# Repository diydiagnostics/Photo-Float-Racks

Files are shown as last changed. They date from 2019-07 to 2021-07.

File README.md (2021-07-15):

## Photo-Float-Racks

## Welcome to the  [DIY Diagnostics](https://diystream.cns.utexas.edu/ "DIY Diagnostics")  [Freshman Research Initiative](https://cns.utexas.edu/fri "Freshman Research Initiative") repository for improved water bath floats.

This repository was created by Niam Kuttanna, Andrew Kan, and Haroon Dossani under the supervision of Dr. Timothy Riedel. It represents an archive of various designs for 3D printed float racks.

# Table of Contents:
1. [Purpose](#Purpose)
2. [Case Study](#Case-Study)
3. [Designs](#Designs)
4. [3D Printing Specifications](#3D-Printing-Specifications)
5. [3D Printing Guide](#3D-Printing-Guide)

## Purpose
Water bath floats are often not optimized for taking photographs of the reaction tubes during incubation. Often the process of inspecting assays comprises three steps: removing the water bath lid; detaching assay tubes from floating sponges; and holding up tube strips for visual inspection or photography. This yields inconsistent images, wastes valuable time, and introduces a host of factors that can affect the certainty of future results (i.e. temperature variation from leaving the water bath open while removing and replacing reaction tubes).

The combination 0.2 ml tube rack/floats described below simplify the process of running and imaging reactions. They are easily printed with a consumer grade 3D printer and the design files are downloadable from this repository. The racks provides for straightforward solution pipetting and ensures a secure hold on the standard 8-tube strip. The tube rack floats so the reactions and rack can be dropped in a water bath directly without the need to transfer the tubes to a float.

These racks are designed for easy assay inspection. The rack designs include a solid color background that enables the entire rack (with tubes) to be lifted out of the water bath and photographed directly. There is no need to transfer the tubes to another holder. 

In addition we have designed a "photo booth" hood that the rack can sit directly on to provide consistent background lighting and focal distance from a smartphone. 

## Case-Study
The [DIY Diagnostics](https://diystream.cns.utexas.edu/ "DIY Diagnostics") lab heavily utilizes the NEB 
[Colorimetric LAMP 2X Master Mix](https://www.neb.com/products/m1800-warmstart-colorimetric-lamp-2x-master-mix-dna-rna#Product%20Information "Colorimetric LAMP 2X Master Mix") to develop sequence specific diagnostic tests. During development we take many photographs over timepoints and the racks described in this repository have enabled more accurate documentation of the diagnostic performance.

ResearchingwithFloatRack

## Designs
alldesigns

First Row (left to right):
- 8C Prototype 1*
- [8C Original.stl]
- [8C Original.stl]**
- [8C Light.stl]
- [3C - Original.stl]
- [IS - Horizontal.stl]

Second Row (left to right):
- LAMP Box Prototype 1
- 16C Sled*
- [8C Side Clip Handle.stl]
- [8C Side Clip Handle + Backdrop.stl]
- [16C Peg Handle.stl]**
- IS Vertical Prototype 1*

Third Row (left to right):
- [16C Dual Handle.stl]
- [16C Peg Handle.stl]**
- [16C Peg Handle.stl]
- [16C Peg Handle.stl]
- [16C Clip Handle.stl]
- [IS - Vertical 2.0.stl] - pre-handle clip compatibility

//* Obsolete design
//** PLA, non-recommended material

### [16 Capacity Designs](https://github.com/diydiagnostics/LAMP-Float-Racks/tree/master/16%20Capacity%20Designs)

### [8 Capacity Designs](https://github.com/diydiagnostics/LAMP-Float-Racks/tree/master/8%20Capacity%20Designs)

### [9 Capacity Designs](https://github.com/diydiagnostics/LAMP-Float-Racks/tree/master/9%20Capacity%20Designs)

### [Imaging Systems](https://github.com/diydiagnostics/LAMP-Float-Racks/tree/master/Imaging%20System%20Designs)

### [Miscellaneous Designs](https://github.com/diydiagnostics/LAMP-Float-Racks/tree/master/Miscellaneous%20Designs)

## 3D Printing Specifications

- Recommended: ABS filament only for float rack use due to its temperature resistance at 60-70℃

- 🔥 = Developer's Choice

Design Name | Filament  | 3D Printer  | Extrusion Speed | Head/Bed Temperature (℃)  | Estimated Print Time
----- | ------  | --------- | --------- | ---------|  --------
[16C Dual Handle.stl] (🔥)  | ABS | Craftbot 2.0  | 50-200 mm/s | 250/110 | 1 hour
[16C Dual Handle.stl] | PLA | Craftbot 2.0  | 50-200 mm/s | 215/60  | 1 hour
[16C Peg Handle.stl] | ABS | Craftbot 2.0  |  50-200 mm/s | 250/110 | 45 minutes
[16C Clip Handle.stl] | PLA | Craftbot 2.0  | 50-200 mm/s | 215/60 | 50 minutes
[8C Backdrop.stl] (🔥)  | ABS | Craftbot 2.0  | 50-200 mm/s | 250/110 | 40 minutes
[8C Light.stl] (🔥)  | ABS | Craftbot 2.0  |  50-200 mm/s | 250/110 | 25 minutes
[8C Original.stl] | ABS | Craftbot 2.0  | 50-200 mm/s | 250/110 | 40 minutes
[8C Side Clip Handle.stl] | ABS | Craftbot 2.0  | 50-200 mm/s | 250/110 | 40 minutes
[8C Side Clip Handle + Backdrop.stl] | ABS | Craftbot 2.0  | 50-200 mm/s | 250/110 | 40 minutes
[8C Slot Handle.stl]  | ABS | Craftbot 2.0  | 50-200 mm/s | 250/110 | 40 minutes
[8C Thumb Divots.stl] | ABS | Craftbot 2.0  | 50-200 mm/s | 250/110 | 40 minutes
[9C - Original.stl] | ABS | Craftbot 2.0  | 50-200 mm/s | 250/110 | 45 minutes
[IS - Horizontal.stl]  | ABS/PLA | Craftbot 2.0  |  50-200 mm/s | 250/110 or 215/60 | 4 hours +
[IS - Vertical.stl]  | ABS/PLA | Craftbot 2.0  |  50-200 mm/s | 250/110 or 215/60 | 4 hours +
[IS - Vertical 2.0.stl]   | ABS/PLA | Craftbot 2.0  |  50-200 mm/s | 250/110 or 215/60 | 4.5 hours +
[IS - Vertical 3.0.stl] (🔥)  | ABS/PLA | Craftbot 2.0  | 50-200 mm/s | 250/110 or 215/60 | 4.5 hours +

## 3D Printing Guide
To print one of these designs, follow the steps below.
1. Download the STL file to a laptop or desktop computer.
2. Load the STL file in a 3D printing software, such as Ultimaker Cura or Craftware.
3. Slice the STL file and convert it to a GCODE file.
4. Load the GCODE file onto an appropriate device for connecting to the printer, navigate to the necessary print startup menu, and start the print. Ensure sufficient filament is available.
- For an Ultimaker 2.0 printer: export the GCODE file to an SD card and insert the SD card into the printer. Select the "Print" option, locate the respective file, and start the print.
- For a Craftbot printer: a) copy the GCODE file onto a USB and insert the USB into the printer; b) connect to the printer over Wifi and start the print directly from Craftware; or c) connect to the printer using a USB A-B cable and start the print directly from Craftware.

[16C Dual Handle.stl]: https://github.com/diydiagnostics/LAMP-Float-Racks/blob/master/16%20Capacity%20Designs/16C%20-%20Dual%20Handle.stl
[16C Dual Handle.stl]: https://github.com/diydiagnostics/LAMP-Float-Racks/blob/master/16%20Capacity%20Designs/16C%20-%20Dual%20Handle.stl
[16C Peg Handle.stl]: https://github.com/diydiagnostics/LAMP-Float-Racks/blob/master/16%20Capacity%20Designs/16C%20-%20Peg%20Handle.stl
[16C Clip Handle.stl]: https://github.com/diydiagnostics/LAMP-Float-Racks/blob/master/16%20Capacity%20Designs/16C%20-%20Clip%20Handle.stl
[8C Backdrop.stl]: https://github.com/diydiagnostics/LAMP-Float-Racks/blob/master/8%20Capacity%20Designs/8C%20-%20Backdrop.stl
[8C Light.stl]: https://github.com/diydiagnostics/LAMP-Float-Racks/blob/master/8%20Capacity%20Designs/8C%20-%20Light.stl
[8C Original.stl]: https://github.com/diydiagnostics/LAMP-Float-Racks/blob/master/8%20Capacity%20Designs/8C%20-%20Original.stl
[8C Side Clip Handle.stl]: https://github.com/diydiagnostics/LAMP-Float-Racks/blob/master/8%20Capacity%20Designs/8C%20-%20Side%20Clip%20Handle.stl
[8C Side Clip Handle + Backdrop.stl]: https://github.com/diydiagnostics/pHLAMP-Float-Racks/blob/master/8%20Capacity%20Designs/8C%20-%20Side%20Clip%20Handle%20%2B%20Backdrop.stl
[8C Slot Handle.stl]: https://github.com/diydiagnostics/LAMP-Float-Racks/blob/master/8%20Capacity%20Designs/8C%20-%20Slot%20Handle.stl
[8C Thumb Divots.stl]: https://github.com/diydiagnostics/LAMP-Float-Racks/blob/master/8%20Capacity%20Designs/8C%20-%20Thumb%20Divots.stl
[9C - Original.stl]: https://github.com/diydiagnostics/LAMP-Float-Racks/blob/master/9%20Capacity%20Designs/9C%20-%20Original.stl
[IS - Horizontal.stl]: https://github.com/diydiagnostics/LAMP-Float-Racks/blob/master/Imaging%20System%20Designs/IS%20-%20Horizontal.stl
[IS - Vertical.stl]: https://github.com/diydiagnostics/LAMP-Float-Racks/blob/master/Imaging%20System%20Designs/IS%20-%20Vertical.stl
[IS - Vertical 2.0.stl]: https://github.com/diydiagnostics/LAMP-Float-Racks/blob/master/Imaging%20System%20Designs/IS%20-%20Vertical%202.0.stl
[IS - Vertical 3.0.stl]: https://github.com/diydiagnostics/LAMP-Float-Racks/blob/master/Imaging%20System%20Designs/IS%20-%20Vertical%203.0.stl
[3C - Original.stl]: https://github.com/diydiagnostics/pHLAMP-Float-Racks/blob/master/Miscellaneous%20Designs/3C%20-%20Original.stl

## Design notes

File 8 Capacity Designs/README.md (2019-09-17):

This folder contains the STL files for all 8 capacity tube rack variants.

## Included Designs

<p align="center">
  8C - Original<br> 
  
</p>

<p align="center">
  8C - Backdrop<br> 
  
</p>

<p align="center">
  8C - Light<br> 
  
</p>

<p align="center">
  8C - Side Clip Handle<br> 
  
</p>

<p align="center">
  8C - Side Clip Handle + Backdrop<br> 
  
</p>

<p align="center">
  8C - Slot Handle<br> 
  
</p>

<p align="center">
  8C - Thumb Divots<br> 
  
</p>

8 capacity tube racks are built to hold a single 8-tube strip. Light and versatile, these designs allow for a variety of different features. Some designs also include handle compatibility; these handles require high precision printing to fully function.

We recommend the 8C Backdrop and 8C Light designs to start. The former is best suited for imaging, while the minimalistic design of the latter requires the least amount of material and time to print.

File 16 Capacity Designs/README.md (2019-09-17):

This folder contains the STL files for all 16 capacity tube rack variants.

## Included Designs

<p align="center">
  16C - Clip Handle<br> 
  
</p>

<p align="center">
  16C - Dual Handle<br> 
  
</p>

<p align="center">
  16C - Peg Handle<br> 
  
</p>

16 capacity tube racks are built to hold two 8-tube strips with only a minimal increase in bulk. Each variant features a backdrop for imaging, reduced structural mass for optimized size, and a clip design of your choice.

We recommend the 16C Dual Handle variant to start. This variant includes the option for both a clip-on handle and a peg handle, making it the best choice if you are unsure which handle you prefer.

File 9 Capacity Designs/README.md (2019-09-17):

This folder contains the STL files for all 9 capacity tube rack variants.

## Included Designs

<p align="center">
  9C - Original<br> 
  
</p>

9 capacity tube racks are built to hold three triplicate assays. Retaining most of the benefits of their 8 capacity predecessors, the 9 capacity tube racks sacrifice a larger size for increased convenience. While running triplicate assays using the standard 8-tube strip results in two wasted tubes, 9 capacity tube racks make this a non-issue.

As of July 25th, 2019, the only 9 capacity tube rack design is the 9C Original. This design is ideal for scientists who are accustomed to threefold reaction sets and are looking to minimize wasted equipment.

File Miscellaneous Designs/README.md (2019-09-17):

This folder contains the STL files for all tube rack related designs that do not fit the previous category criteria.

## Included designs

<p align="center">
  3C - Original<br>
  
</p>

As of July 25th, 2019, the only included design is the 3C Original 3 capacity tube rack variant. This design is specifically built for triplicate assays, for cases when a capacity of 8, 9, or 16 is unnecessary.

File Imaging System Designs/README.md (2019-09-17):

This folder contains the STL files for all tube rack imaging system variants.

### Included Designs

<p align="center">
  IS - Horizontal<br>
  
</p>

<p align="center">
  IS - Vertical<br> 
  
</p>

<p align="center">
  IS - Vertical 2.0<br> 
  
</p>

<p align="center">
  IS - Vertical 3.0<br> 
  
</p>

<p align="center">
  IS - Vertical Spacers<br> 
  
</p>

Current imaging system designs are built to accommodate any 8 capacity or 16 capacity tube rack, with 9 capacity rack compatibility planned for future installments. The IS Horizontal variant is best suited for Android smartphones, while the IS Vertical variants are optimized for iPhones but is also compatible with some Android smartphones (including the Galaxy S9).

We recommend the IS Vertical 2.0 and 3.0 variants for their wider array of compatible smartphones, improved spacer system, and universal tube rack handle functionality.

To use any of these designs:
- Simply place a compatible tube rack on one of the two holder rails (either the angled rails or the rear flat rail).
- Next, slot a compatible smartphone - horizontally or vertically depending on the variant - into the camera holder. Additional spacers are available for precise smartphone positioning. The smartphone camera should be aligned with the camera holder aperture on the inside face of the imaging system.
- Focus the camera on the tube rack as necessary, and take a photograph. Be sure to always set up the system under the same conditions, especially with regards to lighting, to guarantee consistent photographs across all imaging sessions.

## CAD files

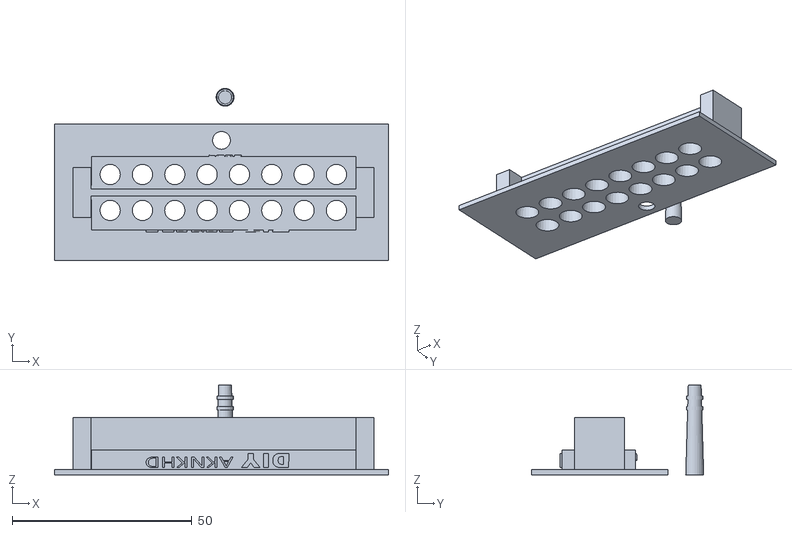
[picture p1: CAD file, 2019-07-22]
16 Capacity Designs/16C - Peg Handle.stl
93.0 x 48.0 x 25.0

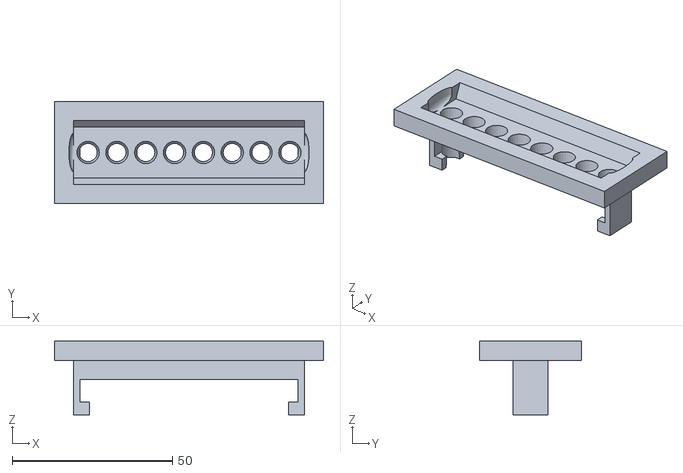
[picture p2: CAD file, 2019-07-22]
8 Capacity Designs/8C - Thumb Divots.stl
84.0 x 32.0 x 23.0

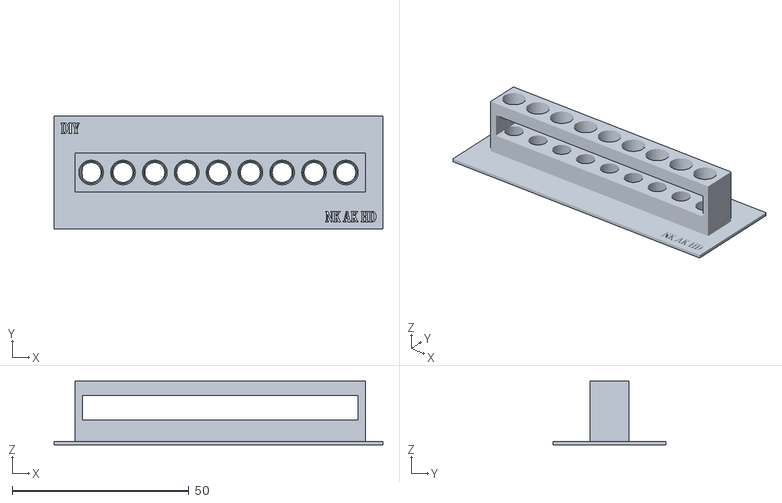
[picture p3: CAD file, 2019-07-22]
9 Capacity Designs/9C - Original.stl
93.0 x 32.0 x 18.0

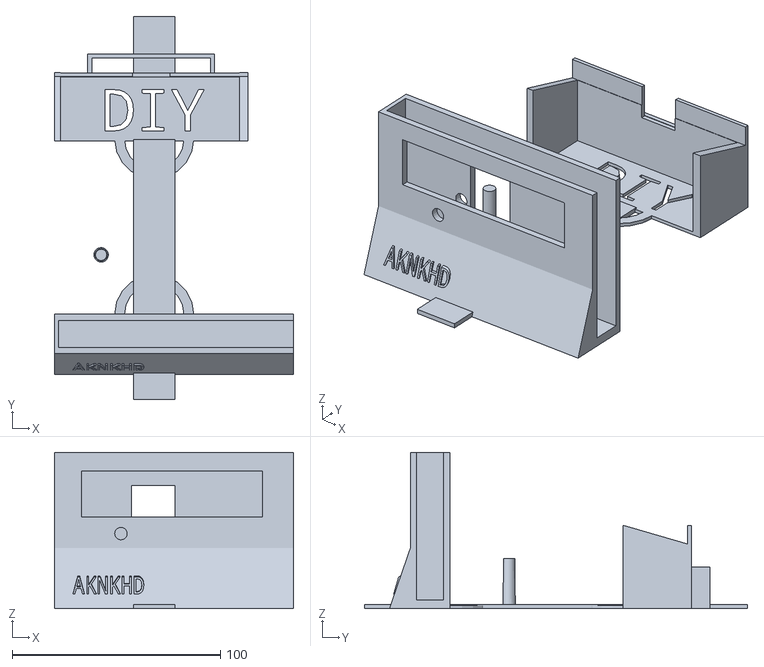
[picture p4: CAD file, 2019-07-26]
Imaging System Designs/IS - Vertical 3.0.stl
115.0 x 184.0 x 75.0

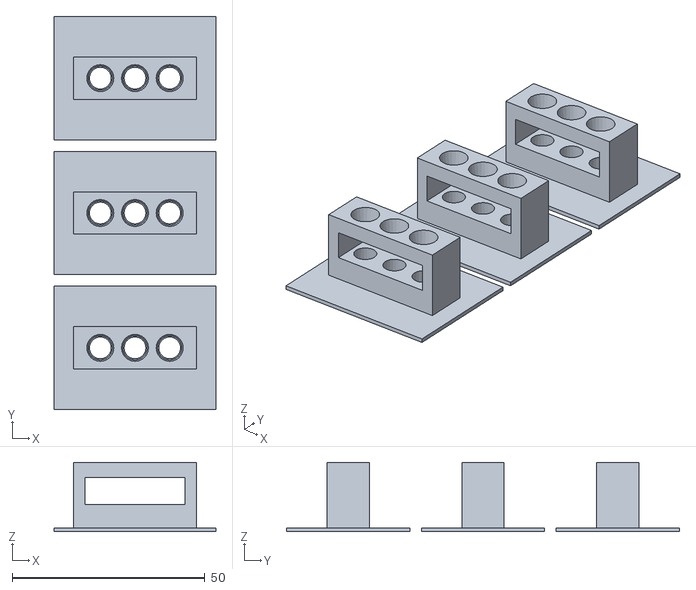
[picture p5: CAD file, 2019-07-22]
Miscellaneous Designs/3C - Original.stl
42.0 x 102.0 x 18.0

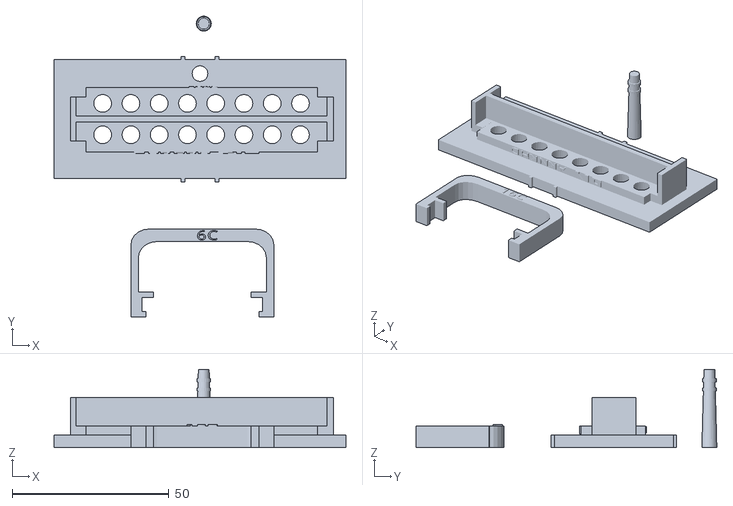
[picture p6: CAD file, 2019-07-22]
16 Capacity Designs/16C - Dual Handle.stl
93.0 x 95.8 x 25.0

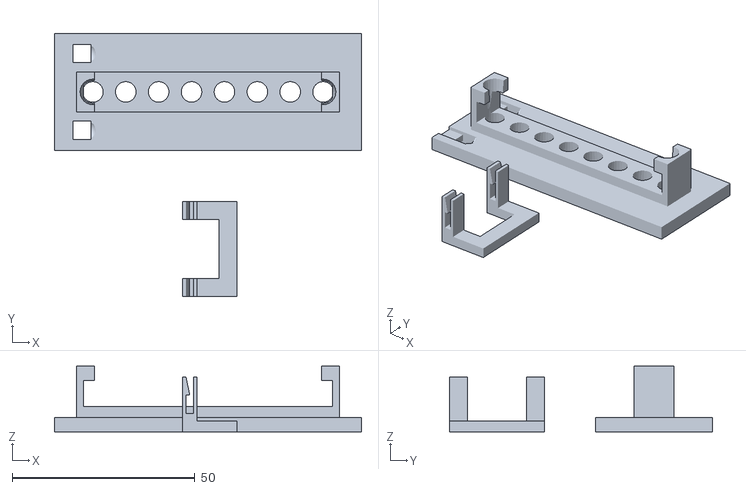
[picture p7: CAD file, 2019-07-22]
8 Capacity Designs/8C - Side Clip Handle.stl
84.0 x 72.0 x 18.0

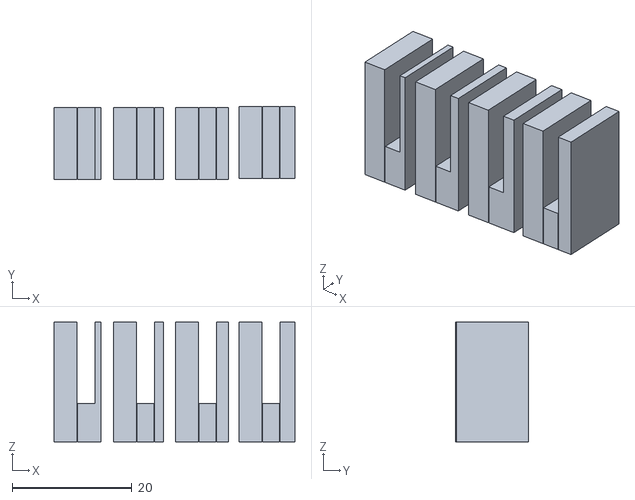
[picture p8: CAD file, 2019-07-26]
Imaging System Designs/IS - Vertical Spacers.stl
40.2 x 12.1 x 20.0

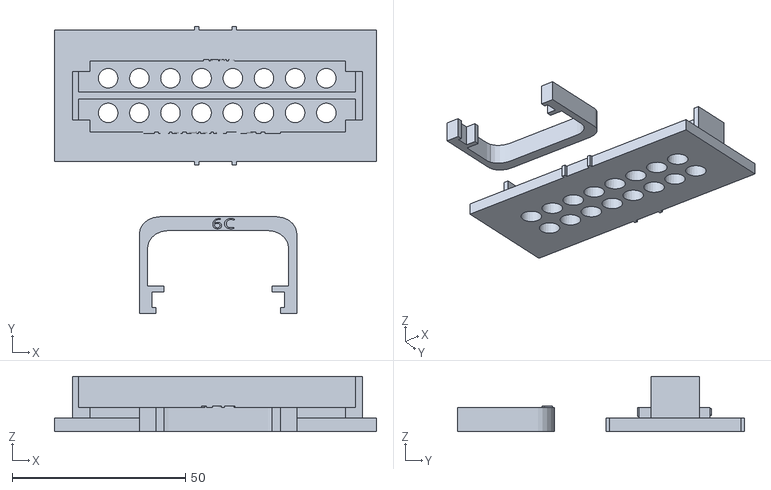
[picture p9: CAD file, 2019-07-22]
16 Capacity Designs/16C - Clip Handle.stl
93.0 x 83.0 x 16.0

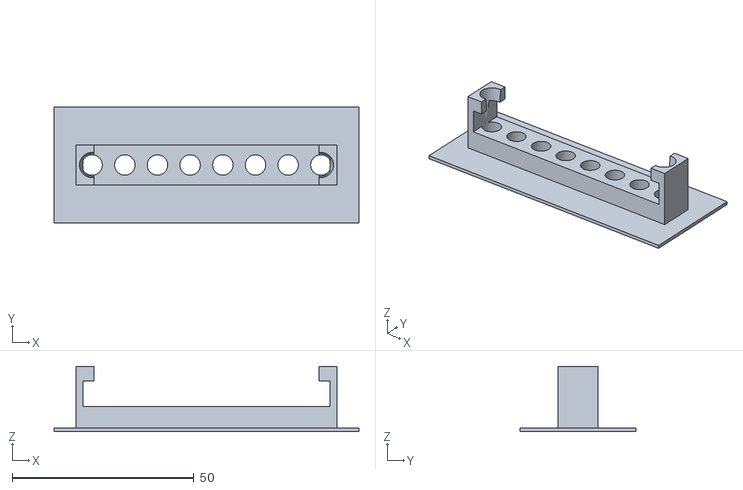
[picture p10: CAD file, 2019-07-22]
8 Capacity Designs/8C - Light.stl
84.0 x 32.0 x 18.0

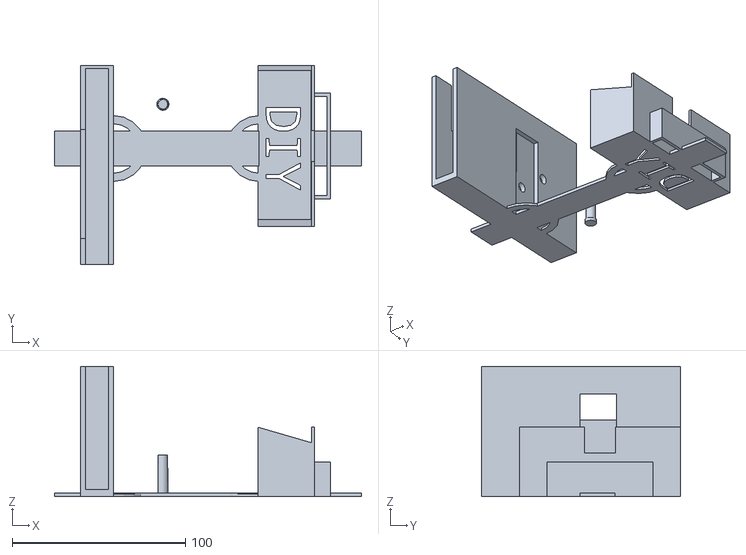
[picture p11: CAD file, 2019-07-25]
Imaging System Designs/IS - Vertical 2.0.stl
177.0 x 115.0 x 75.0

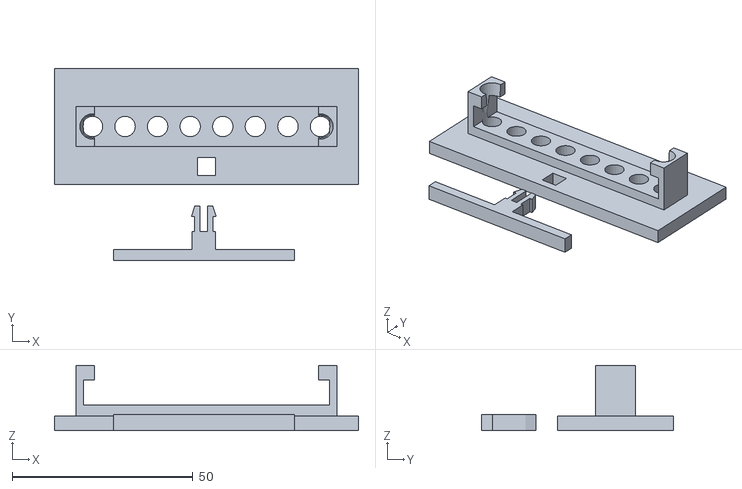
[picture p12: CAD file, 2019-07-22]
8 Capacity Designs/8C - Slot Handle.stl
84.0 x 53.0 x 18.0

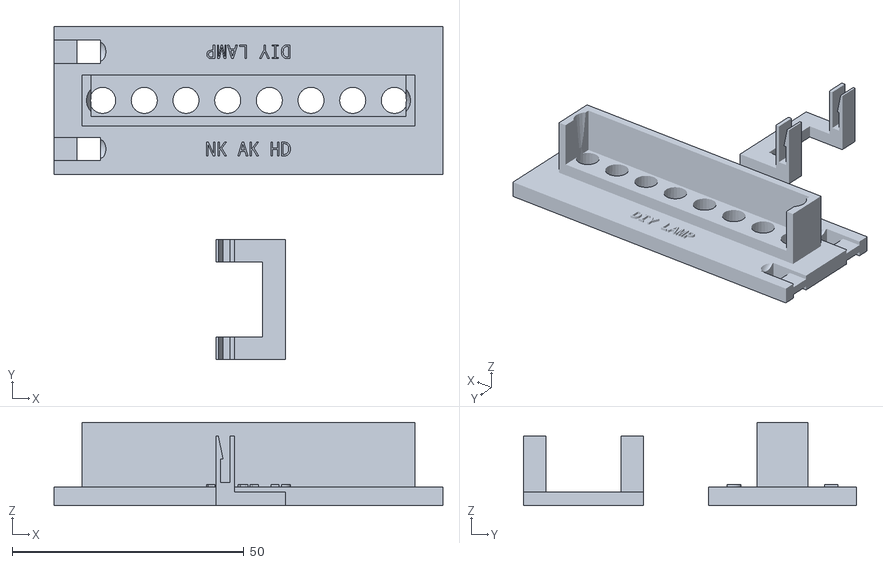
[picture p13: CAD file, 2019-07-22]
8 Capacity Designs/8C - Side Clip Handle + Backdrop.stl
84.0 x 72.0 x 18.0

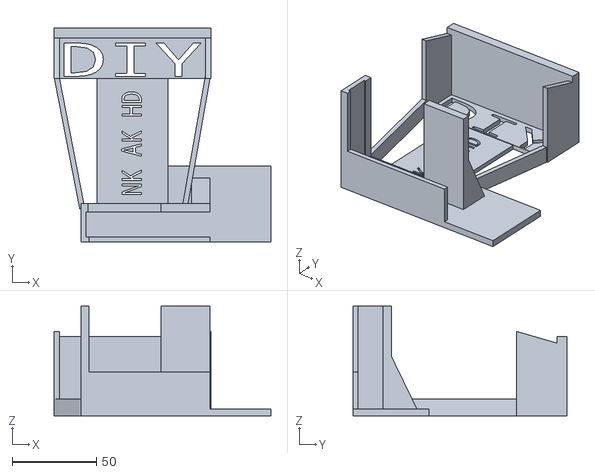
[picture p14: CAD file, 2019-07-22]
Imaging System Designs/IS - Horizontal.stl
128.5 x 127.0 x 65.0

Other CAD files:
Imaging System Designs/IS - Vertical.stl
8 Capacity Designs/8C - Backdrop.stl
8 Capacity Designs/8C - Original.stl

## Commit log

2019-07-22 Created 8C slot handle folder
2019-07-22 Uploaded 16C design files
    [16C - Clip Handle.stl, 16C - Dual Handle.stl, 16C - Peg Handle.stl]
2019-07-22 Uploaded 8C design files
    [8C - Backdrop.stl, 8C - Light.stl, 8C - Original.stl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]
2019-07-22 Uploaded 16C clip handle
    [16C - Clip Handle.stl]
2019-07-22 Uploaded IS design files
    [IS - Horizontal.stl, IS - Vertical.stl]
2019-07-22 Uploaded 9C design file
    [9C - Original.stl]
2019-07-22 Uploaded 3C design file
    [3C - Original.stl]
2019-07-22 Uploaded 9C original
    [9C - Original.stl]
2019-07-22 Uploaded 16C dual handle
    [16C - Dual Handle.stl]
2019-09-17 Removed to rename
    [8C - Slot Handle + Backdrop.stl]
2019-10-04 Added basic 3D printing guide
2019-10-24 adding case study of pH - LAMP
2019-10-24 added Case-Study
